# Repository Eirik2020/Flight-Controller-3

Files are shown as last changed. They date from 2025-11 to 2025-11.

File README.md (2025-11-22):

<p align="center" width="100%">
  
</p>

<h1 align="center">Board Name</h1>

<p align="center" width="100%">
  <a href="/actions/workflows/ci.yaml">
    CI Badge
  </a>
</p>

<p align="center" width="100%">
    
</p>

***

<p align="center">
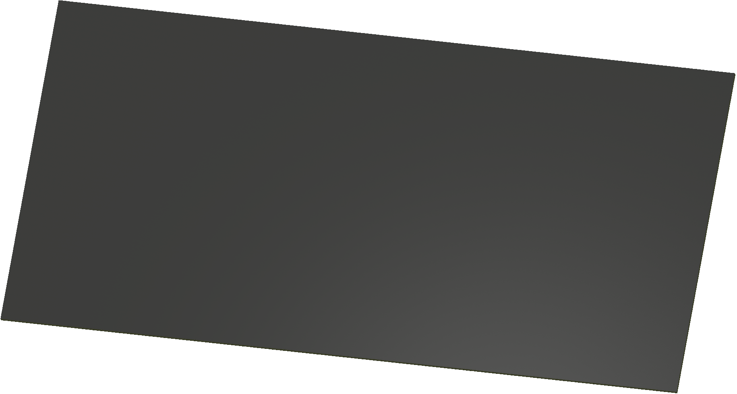
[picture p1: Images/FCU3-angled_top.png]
3D Top Angled
  
&nbsp; &nbsp; &nbsp; &nbsp;
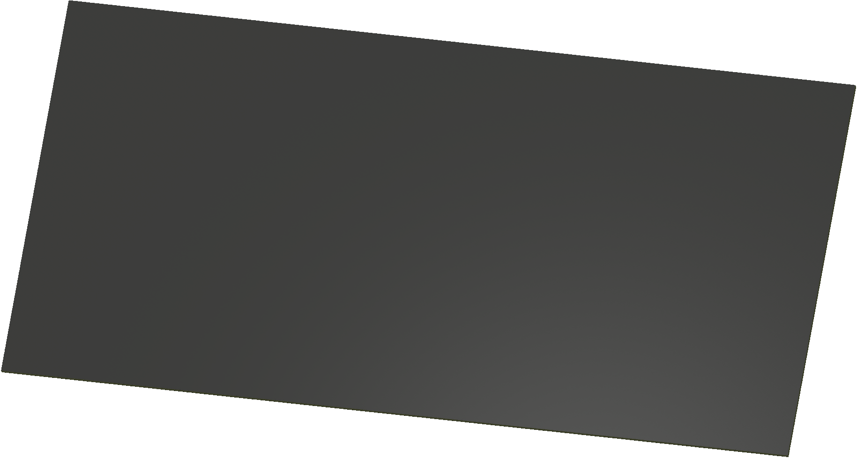
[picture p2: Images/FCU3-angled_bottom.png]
3D Bottom Angled
  
</p>

***

## SPECIFICATIONS

| Parameter | Value | 
| --- | --- |
| Dimensions | N/A × N/A mm |

***

## DIRECTORY STRUCTURE

    .
    ├─ Computations       # Misc calculations
    ├─ HTML               # HTML files for generated webpage
    ├─ Images             # Pictures and renders
    │
    ├─ kibot_resources    # External resources for KiBot
    │  ├─ colors          # Color theme for KiCad
    │  ├─ fonts           # Fonts used in the project
    │  ├─ scripts         # External scripts used with KiBot
    │  └─ templates       # Templates for KiBot generated reports
    │
    ├─ kibot_yaml         # KiBot YAML config files
    ├─ KiRI               # KiRI (PCB diff viewer) files
    │
    ├─ lib                # KiCad footprint and symbol libraries
    │  ├─ 3d_models       # Component 3D models
    │  ├─ lib_fp          # Footprint libraries
    │  └─ lib_sym         # Symbol libraries
    │
    ├─ Logos              # Logos
    │
    ├─ Manufacturing      # Assembly and fabrication documents
    │  ├─ Assembly        # Assembly documents (BoM, pos, notes)
    │  │
    │  └─ Fabrication     # Fabrication documents (ZIP, notes)
    │     ├─ Drill Tables # CSV drill tables
    │     └─ Gerbers      # Gerbers
    │
    ├─ Report             # Reports for ERC/DRC
    ├─ Schematic          # PDF of schematic
    ├─ Templates          # Title block templates
    ├─ Testing
    │  └─ Testpoints      # Testpoints tables      
    │
    └─ Variants           # Outputs for assembly variants

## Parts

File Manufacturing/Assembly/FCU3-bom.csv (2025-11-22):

Row | Quantity Per PCB | References | Value | Datasheet | Footprint | Description | Manufacturer | Manufacturer Part Number | Supplier Part Number
1 | 2 | C15 C16 | 27pF | ~ | C_0603_1608Metric_Pad1.08x0.95mm_HandSolder | Unpolarized capacitor, small symbol
2 | 9 | C3 C4 C5 C6 C12 C13 C14 C17 C18 | 100nF | ~ | C_0603_1608Metric_Pad1.08x0.95mm_HandSolder | Unpolarized capacitor, small symbol
3 | 2 | C1 C2 | 1uF | ~ | C_0603_1608Metric_Pad1.08x0.95mm_HandSolder | Unpolarized capacitor
4 | 3 | C7 C8 C9 | 2.2uF | ~ | C_0603_1608Metric_Pad1.08x0.95mm_HandSolder | Unpolarized capacitor, small symbol
5 | 7 | C10 C11 C19 C20 C21 C22 C23 | 10uF | ~ | C_0603_1608Metric_Pad1.08x0.95mm_HandSolder | Unpolarized capacitor, small symbol
6 | 2 | D1 D2 | SS14 | https://www.vishay.com/docs/88746/ss12.pdf | D_SMA | 40V 1A Schottky Diode, SMA
7 | 5 | J1 J2 J4 J5 J6 | SM06B-SRSS-TB_LF__SN_ |  | JST_SM06B-SRSS-TB_LF__SN_ | Generic connector, double row, 02x03, odd/even pin numbering scheme (row 1 odd numbers, row 2 even numbers), script generated (kicad-library-utils/schlib/autogen/connector/) | JST Same Sky
8 | 1 | PS1 | TPSM84338RCJR |  | TPSM84338RCJR |  | Texas Instruments
9 | 1 | Q2 | SS8050 | http://www.secosgmbh.com/datasheet/products/SSMPTransistor/SOT-23/SS8050.pdf | SOT-23 | General Purpose NPN Transistor, 1.5A Ic, 25V Vce, SOT-23
10 | 1 | R4 | 1k | ~ | R_0603_1608Metric_Pad0.98x0.95mm_HandSolder | Resistor, small symbol
11 | 2 | R7 R10 | 4.7k | ~ | R_0603_1608Metric_Pad0.98x0.95mm_HandSolder | Resistor, small symbol
12 | 2 | R9 R15 | 5.1k | ~ | R_0805_2012Metric_Pad1.20x1.40mm_HandSolder | Resistor
13 | 4 | R2 R3 R8 R11 | 10k | ~ | R_0603_1608Metric_Pad0.98x0.95mm_HandSolder | Resistor, small symbol
14 | 1 | R5 | 18k | ~ | R_0603_1608Metric_Pad0.98x0.95mm_HandSolder | Resistor
15 | 1 | R1 | 75k | ~ | R_0603_1608Metric_Pad0.98x0.95mm_HandSolder | Resistor, small symbol
16 | 1 | R6 | 140k | ~ | R_0603_1608Metric_Pad0.98x0.95mm_HandSolder | Resistor
17 | 1 | S1 | TS32-7-35-BK-B-260-RA-SMT-TR |  | SW_TS32-7-35-BK-B-260-RA-SMT-TR |  | Same Sky
18 | 1 | U3 | MCP1700x-330xxTT | http://ww1.microchip.com/downloads/en/DeviceDoc/20001826D.pdf | SOT-23 | 250mA Low Quiscent Current LDO, 3.3V output, SOT-23
19 | 1 | U1 | MPU-6500 |  | QFN40P300X300X95-25N |  | TDK InvenSense
20 | 1 | U5 | STM32F405RGTx | https://www.st.com/resource/en/datasheet/stm32f405rg.pdf | LQFP-64_10x10mm_P0.5mm | STMicroelectronics Arm Cortex-M4 MCU, 1024KB flash, 192KB RAM, 168 MHz, 1.8-3.6V, 51 GPIO, LQFP64
21 | 1 | Y1 | LFXTAL055207Bulk | ~ | Crystal_HC49-4H_Vertical | Two pin crystal

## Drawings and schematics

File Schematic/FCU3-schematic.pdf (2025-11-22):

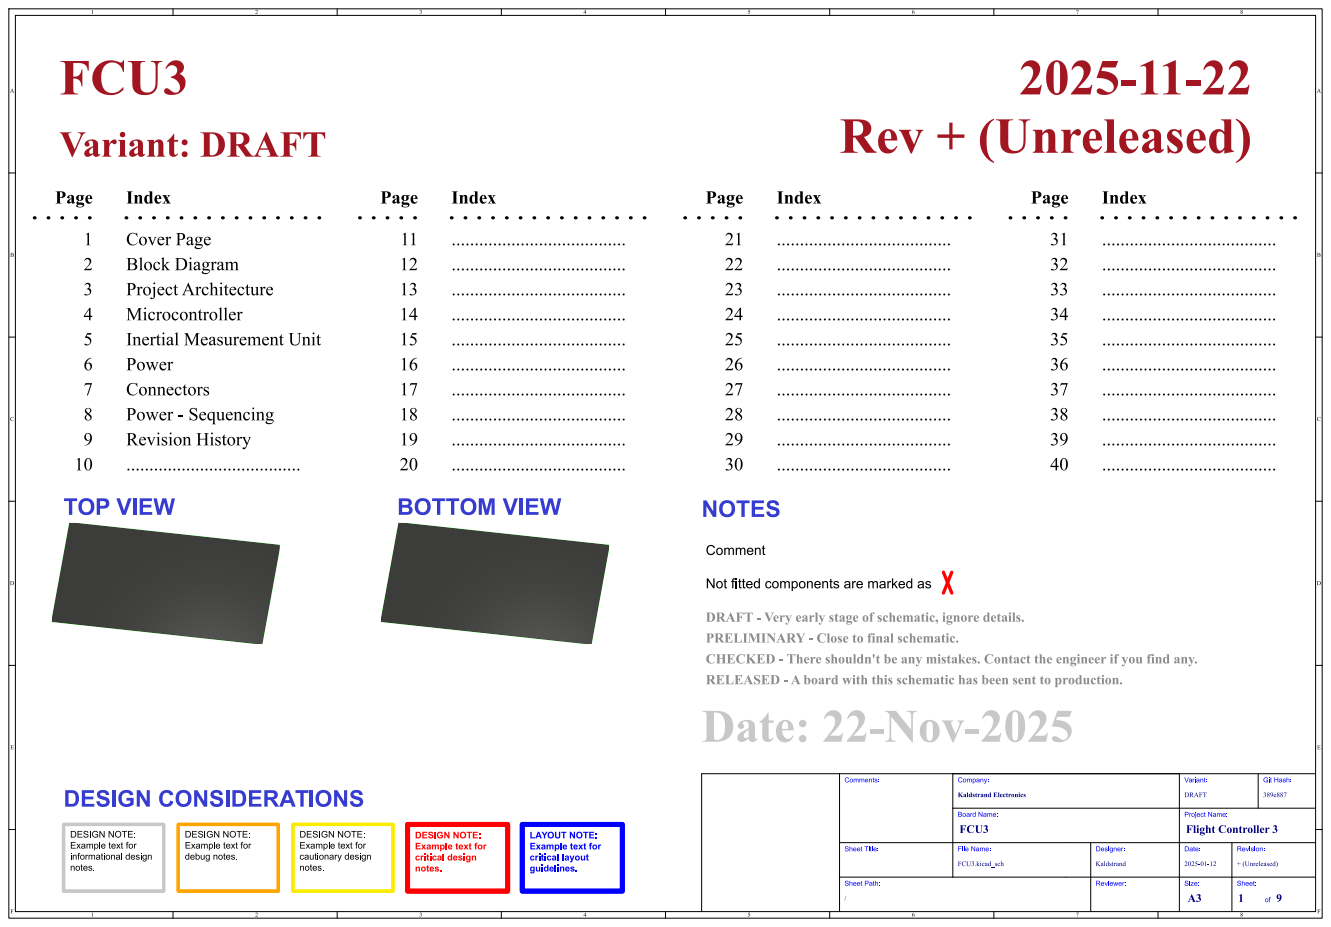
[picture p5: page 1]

...................................... Date:22-Nov-2025
CHECKED - Thereshouldn'tbeanymistakes.Contacttheengineerif youfindany. ......................................

Not fitted components are marked as

DRAFT - Veryearlystageof schematic,ignoredetails.

Revision: + (Unreleased) Date: Project Name: 2025-01-12 Reviewer: Designer:

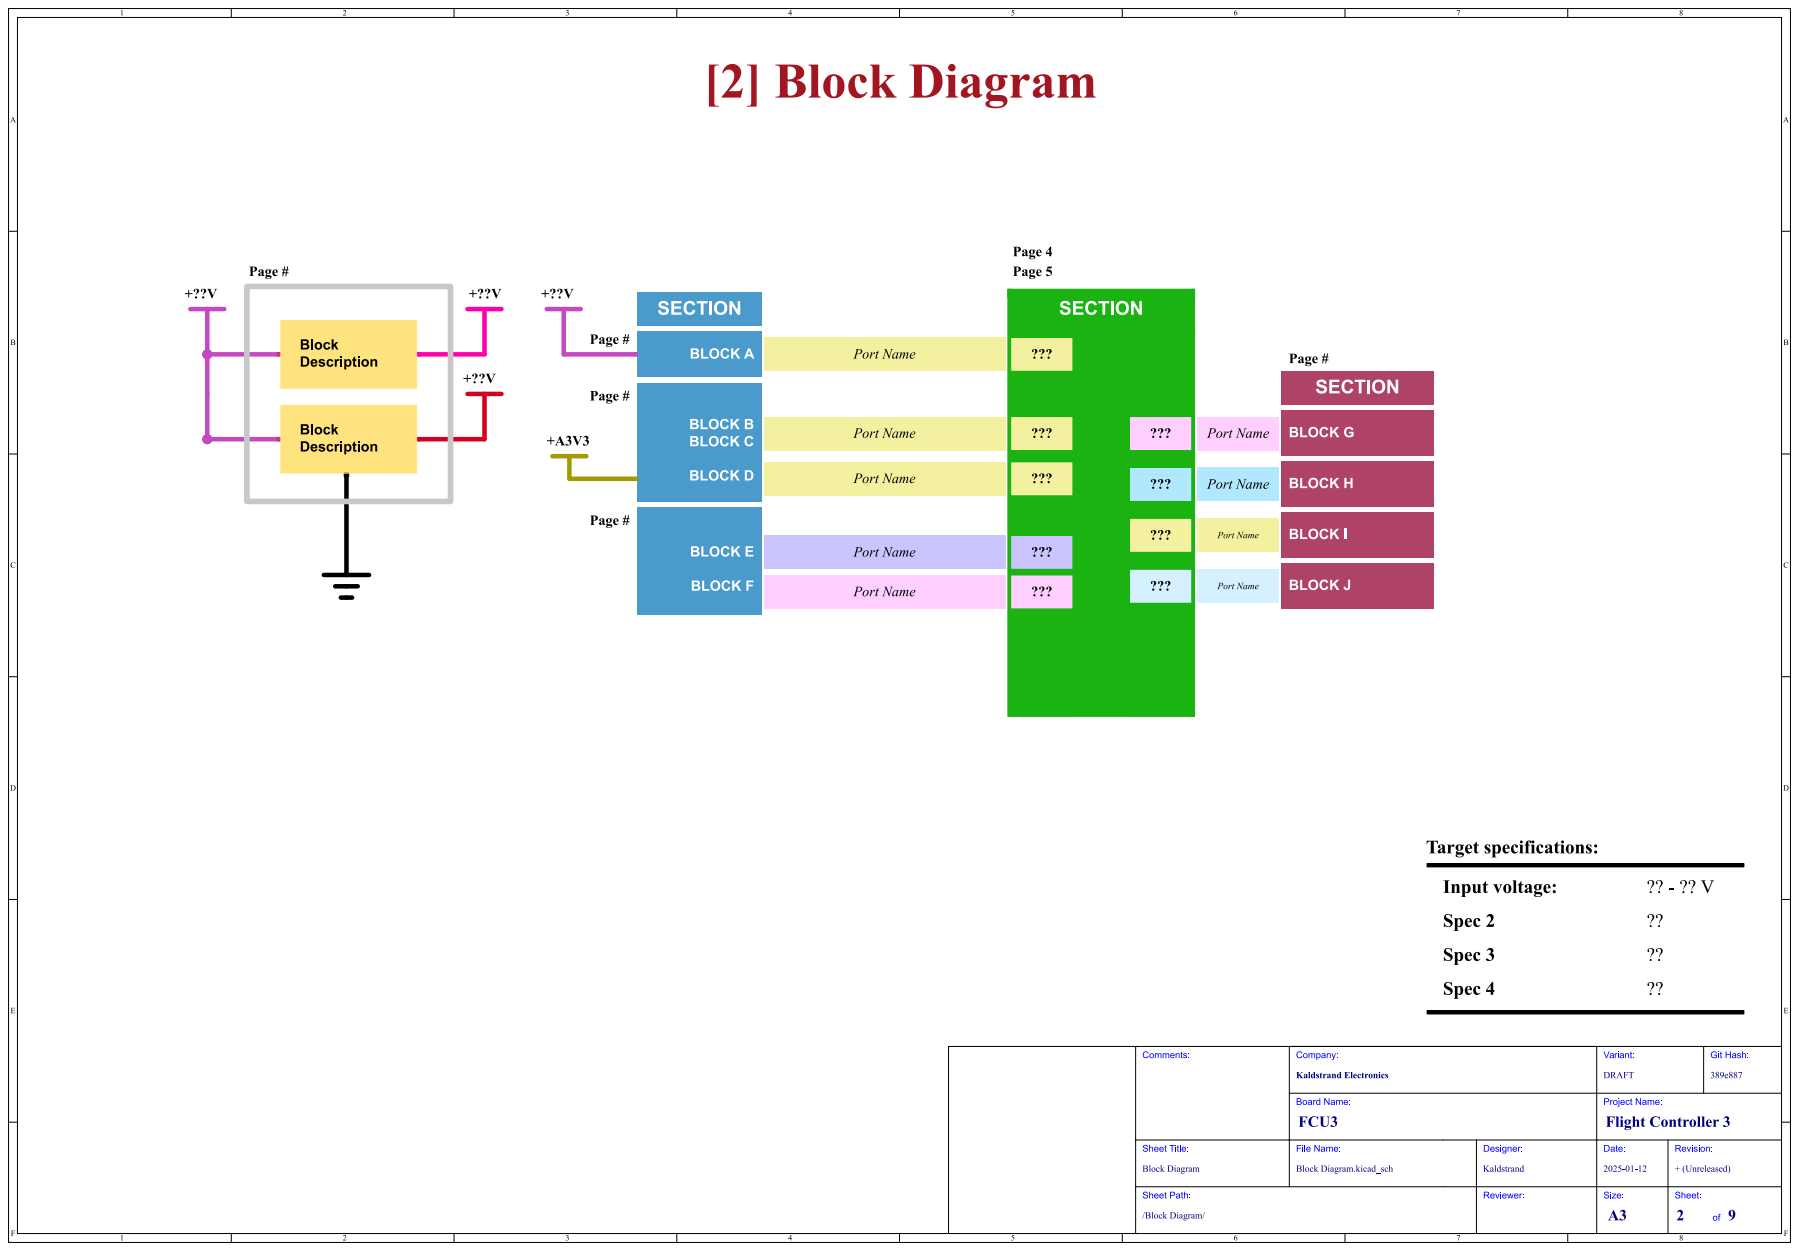
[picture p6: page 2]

Port Name | ??? | Port Name

BLOCK G

Port Name

/Block Diagram/ Sheet Path: Block Diagram

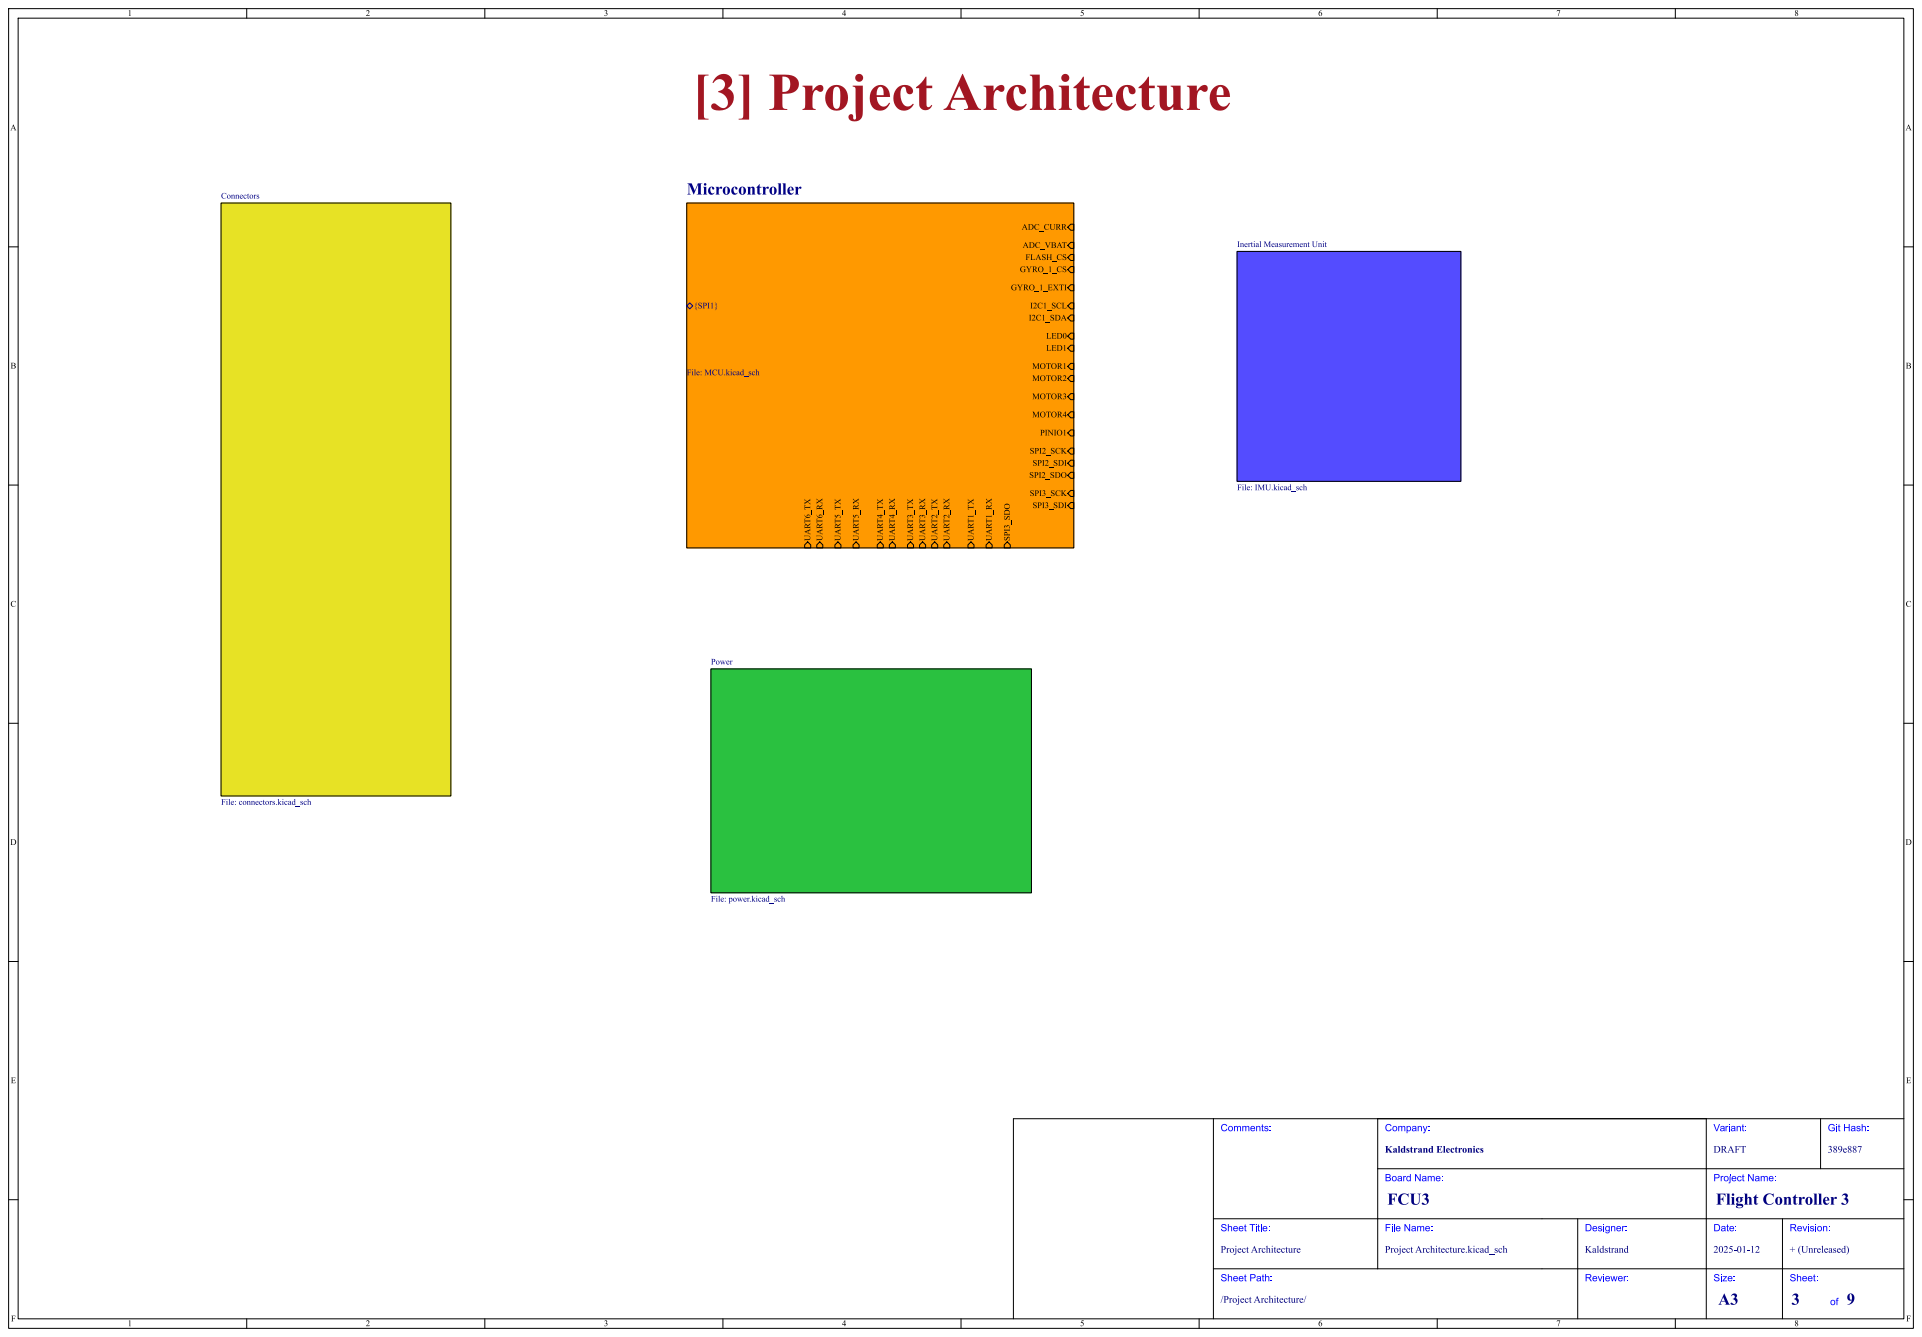
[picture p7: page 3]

Inertial MeasurementUnit File: IMU.kicad_sch Power File: power.kicad_sch

Revision: + (Unreleased) Date: Project Name: 2025-01-12 Reviewer: Designer:

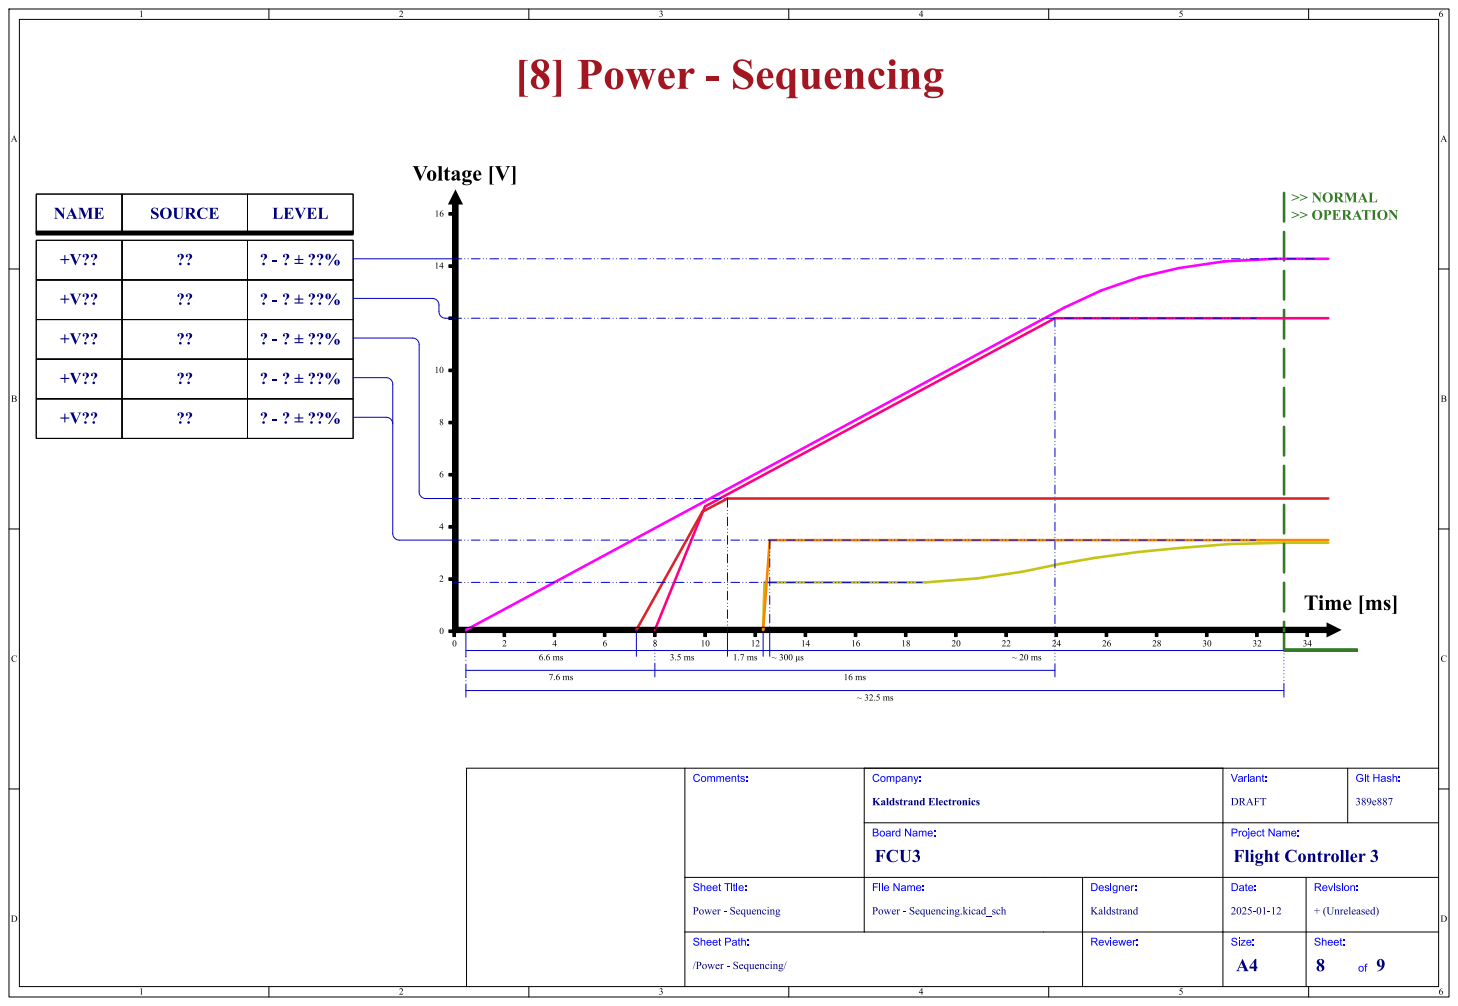
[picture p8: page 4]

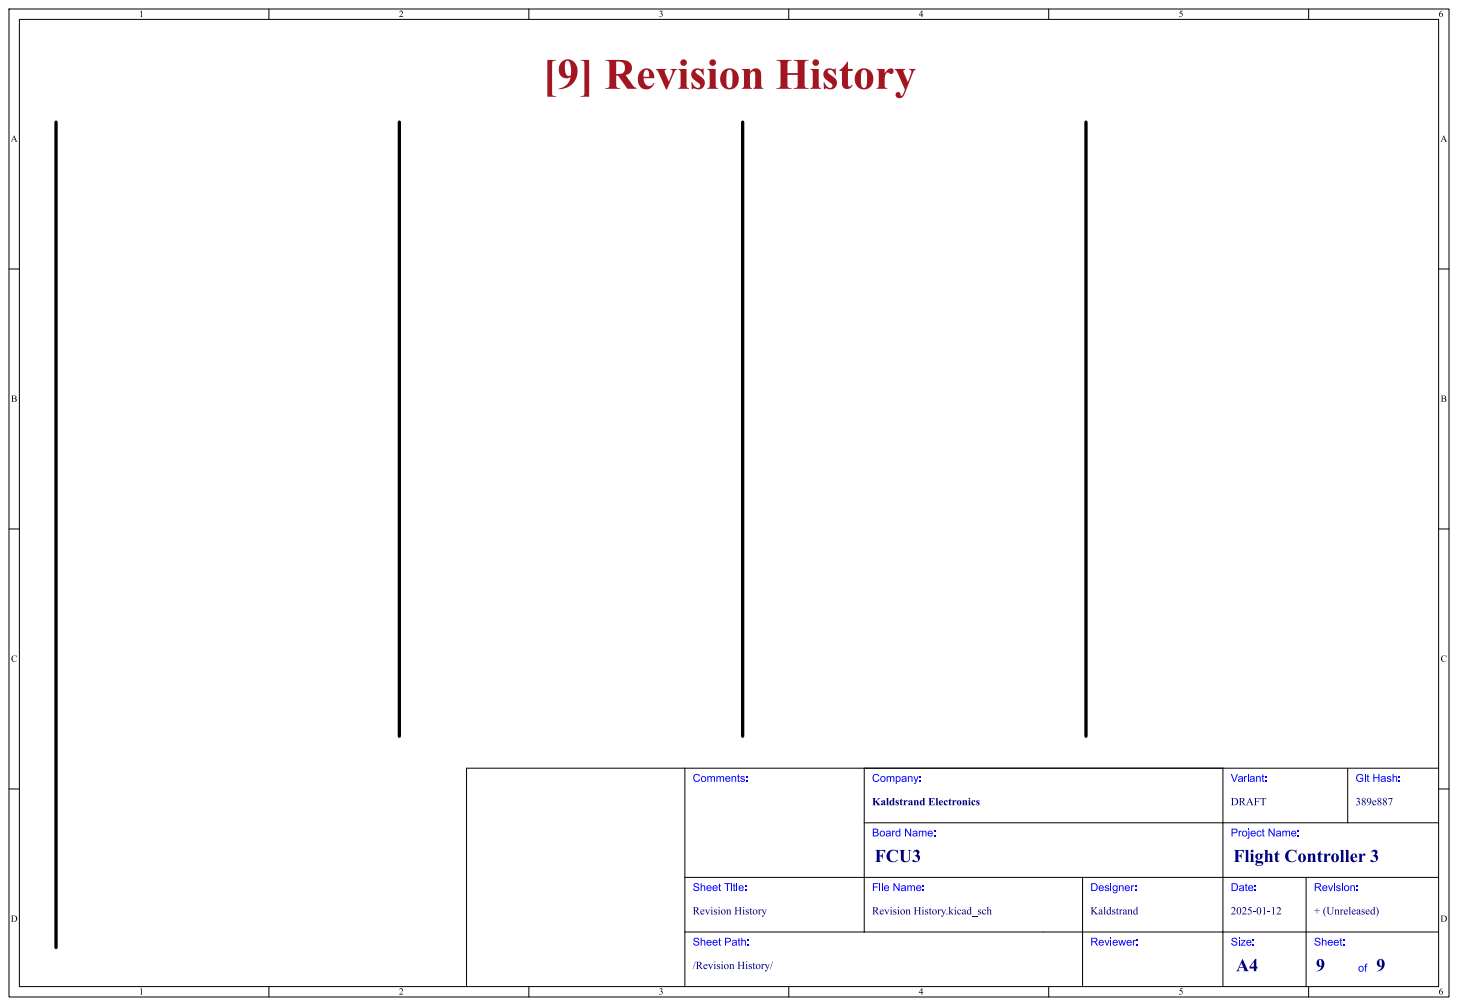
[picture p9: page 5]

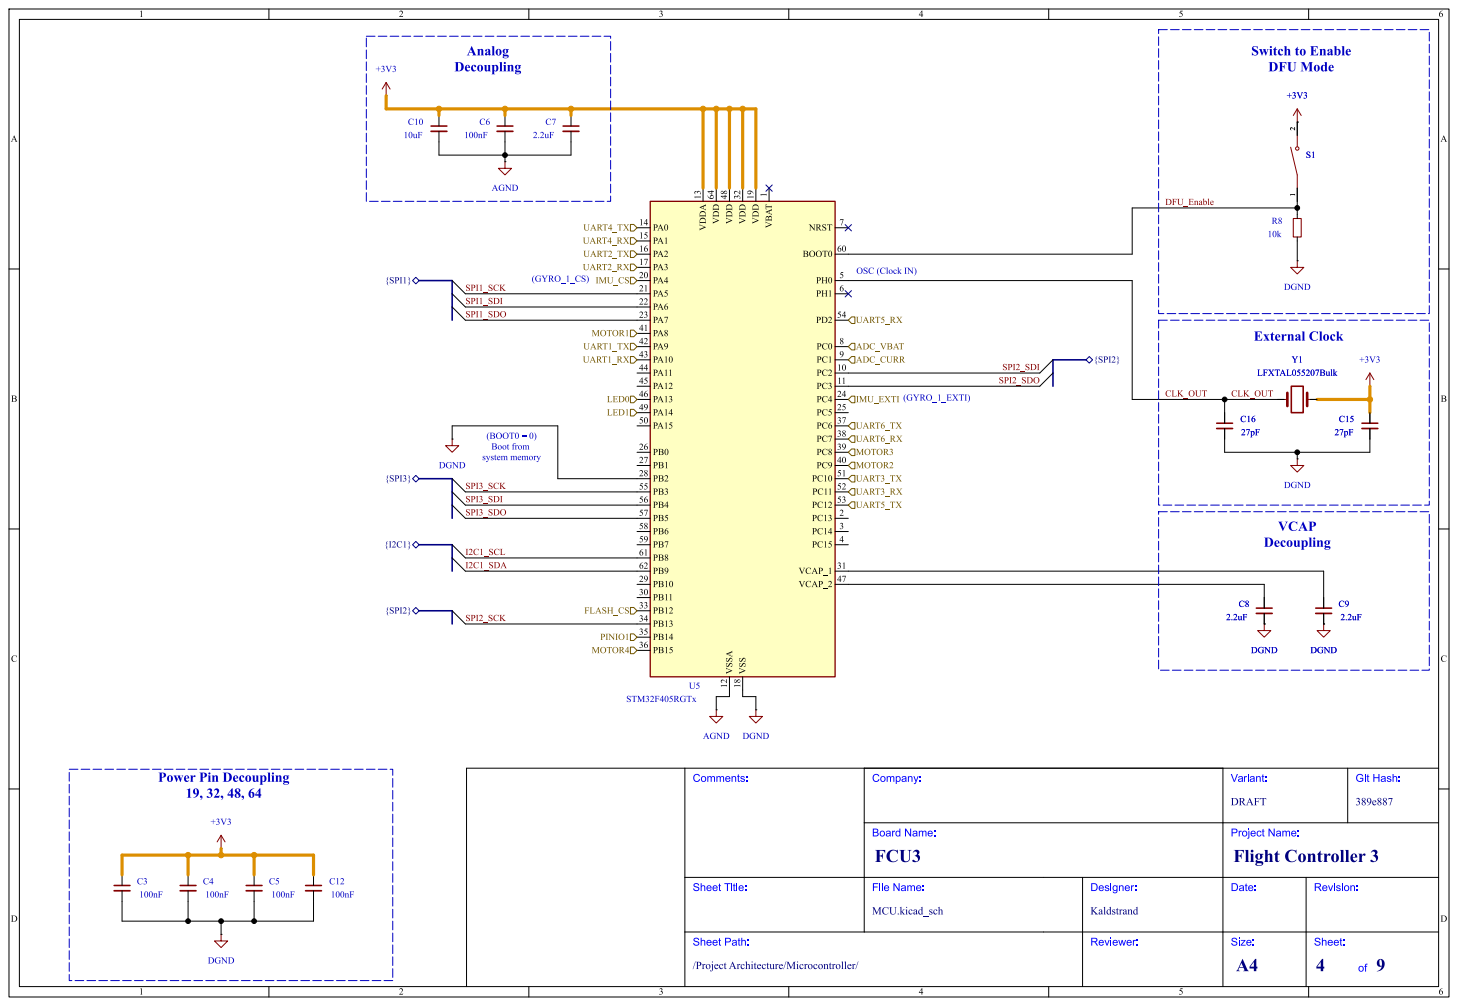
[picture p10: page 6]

1 VDD 19 VDD 32 VSS 18 VDD 48 VSSA 12 VDD 64 VDDA 13 PA0 14 PA1 15 PA2 16 PA3 17 PA4 20 PA5 21 PA6 22 PA7 23 PA8 41 PA9 42 PA10 43 PA11 44 PA12 45 PA13 46 PA14 49 PA15 50 PB0 26 PB1 27 PB2 28 PB3 55 PB4 56 PB5 57 PB6 58 PB7 59 PB8 61 PB9 62 PB10 29 PB11 30 PB12 33 PB13 34 PB14 35 PB15 36 U5 STM32F405RGTx

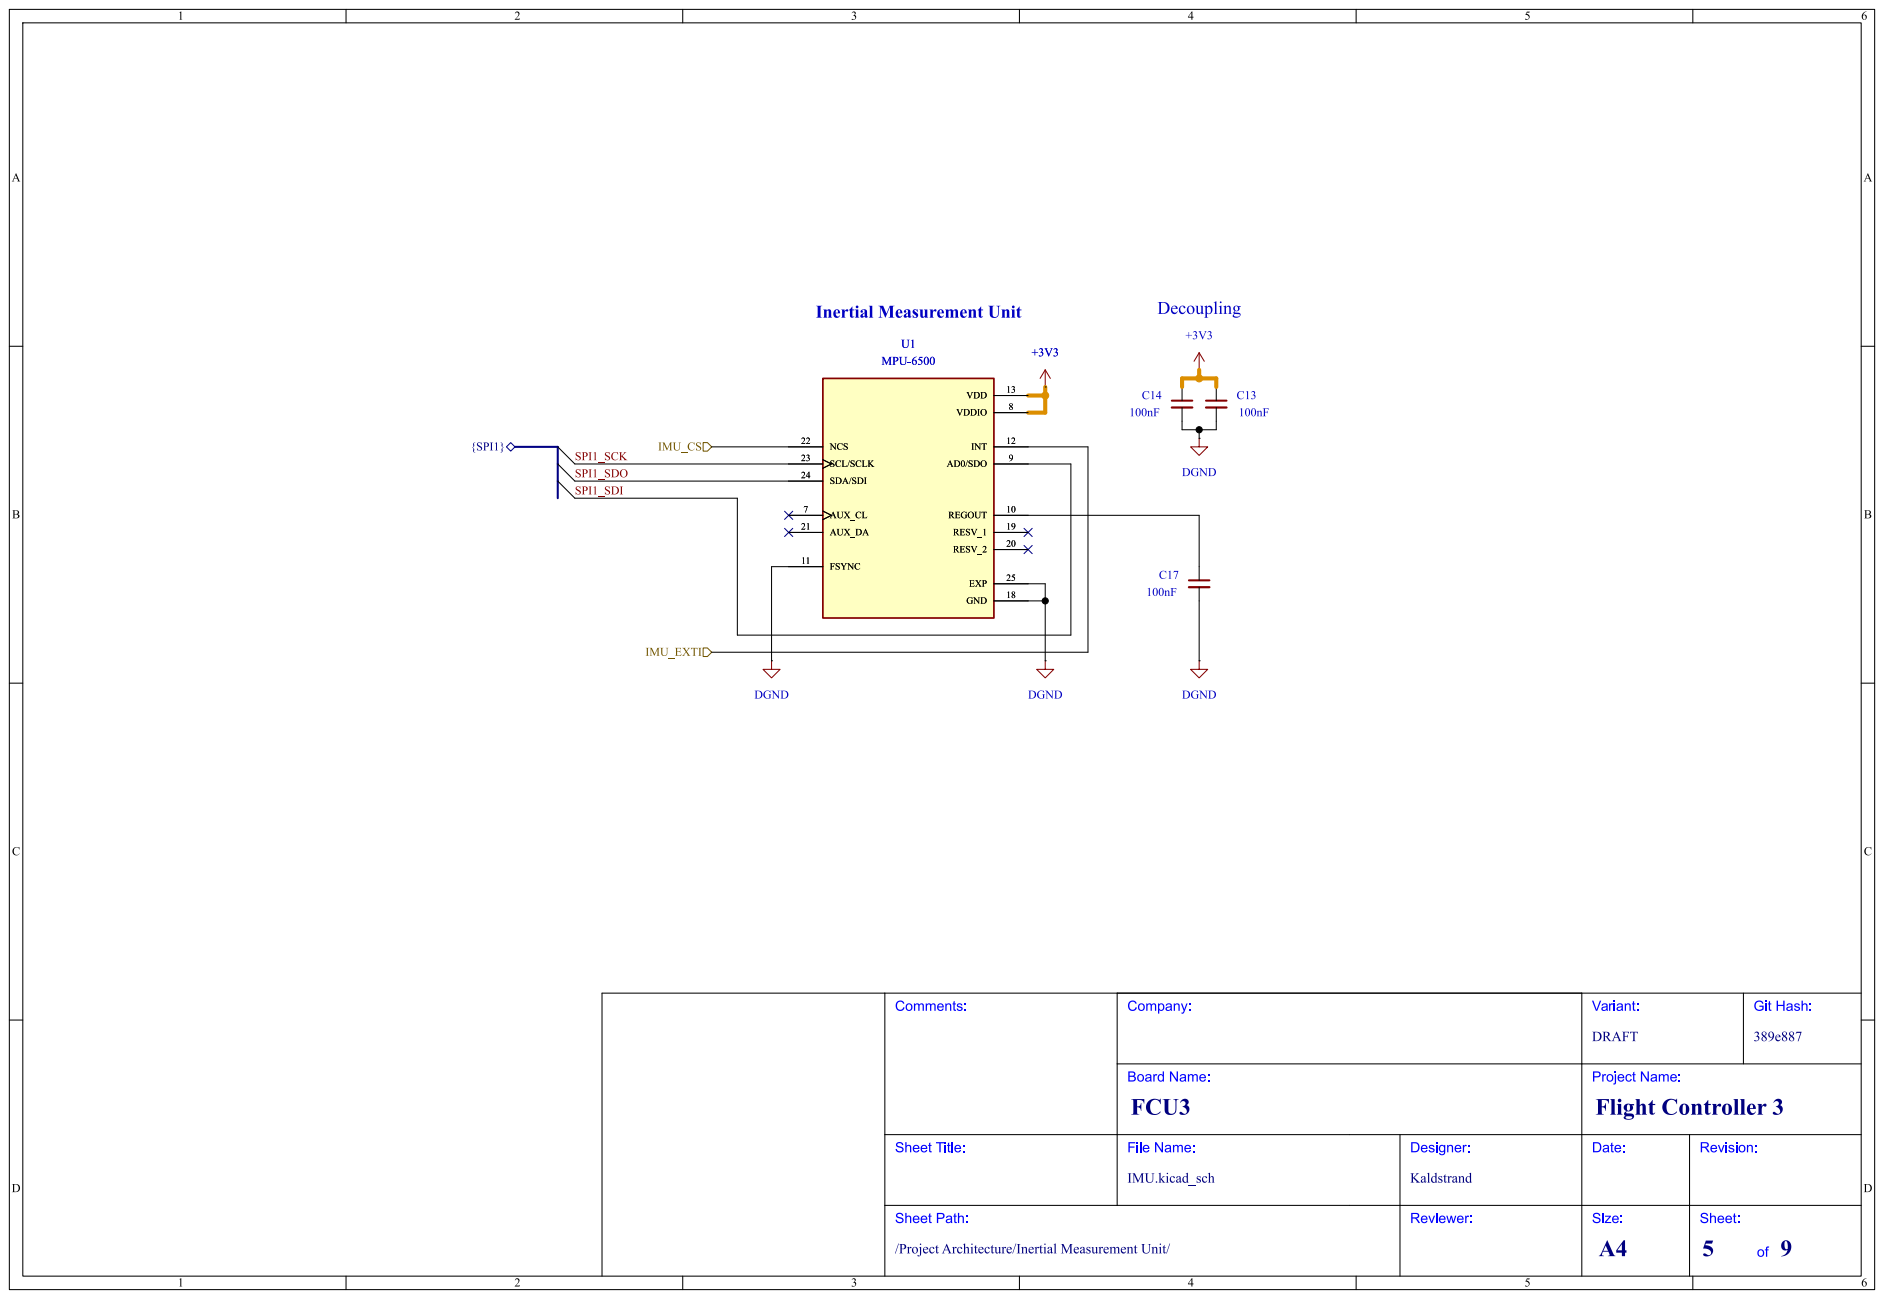
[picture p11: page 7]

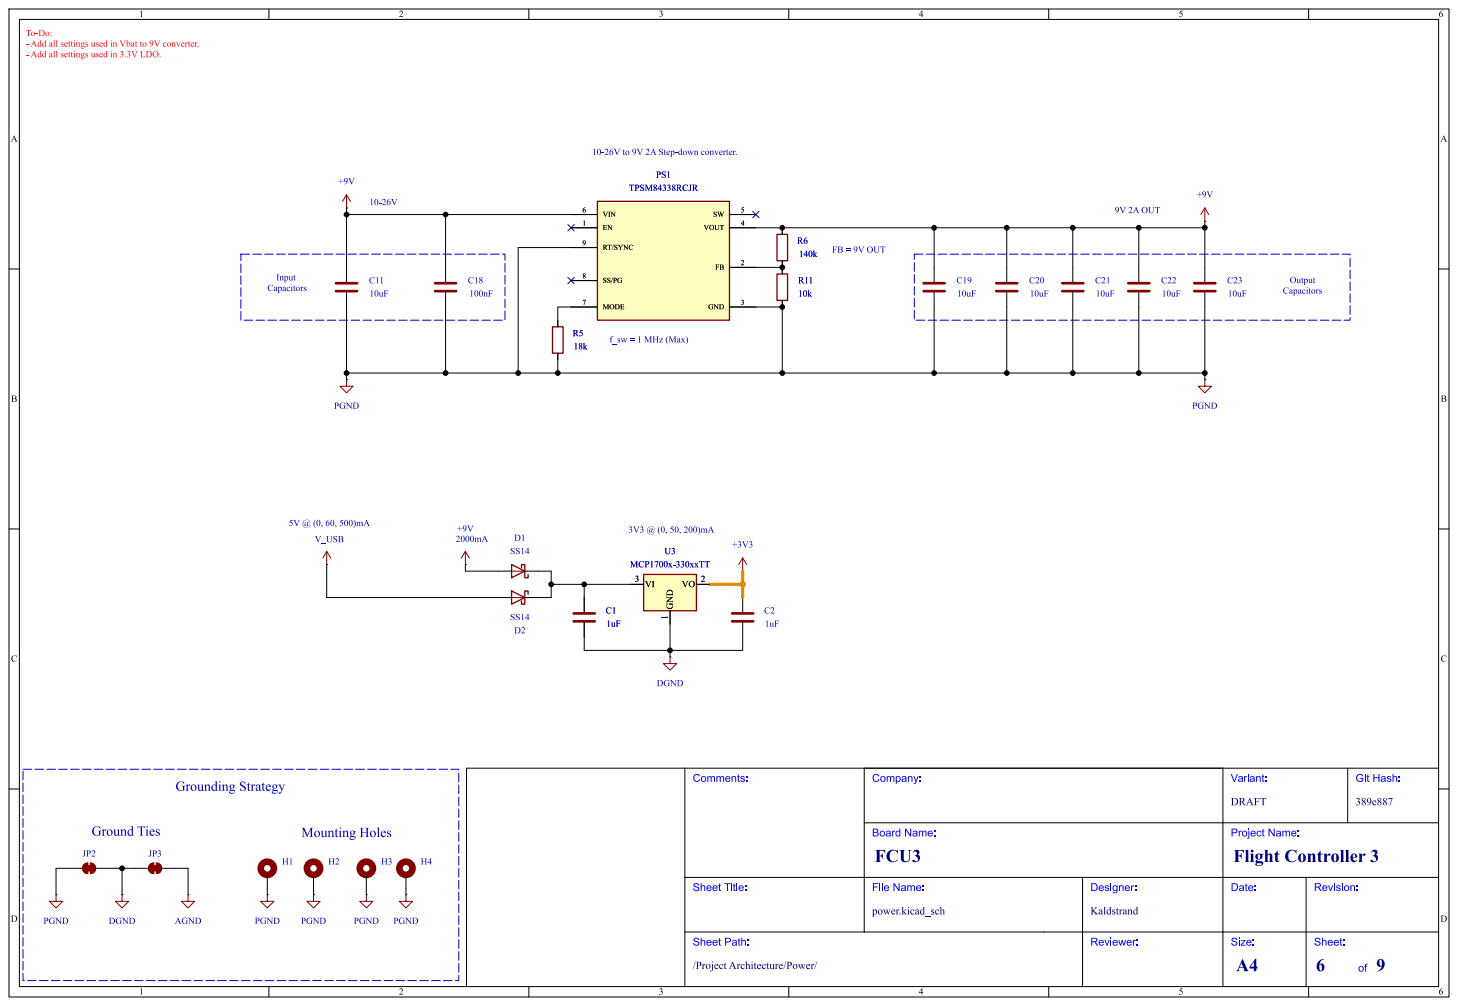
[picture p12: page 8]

f_sw = 1 MHz (Max) 10-26Vto 9V 2A Step-downconverter. 3V3 @(0, 50,200)mA

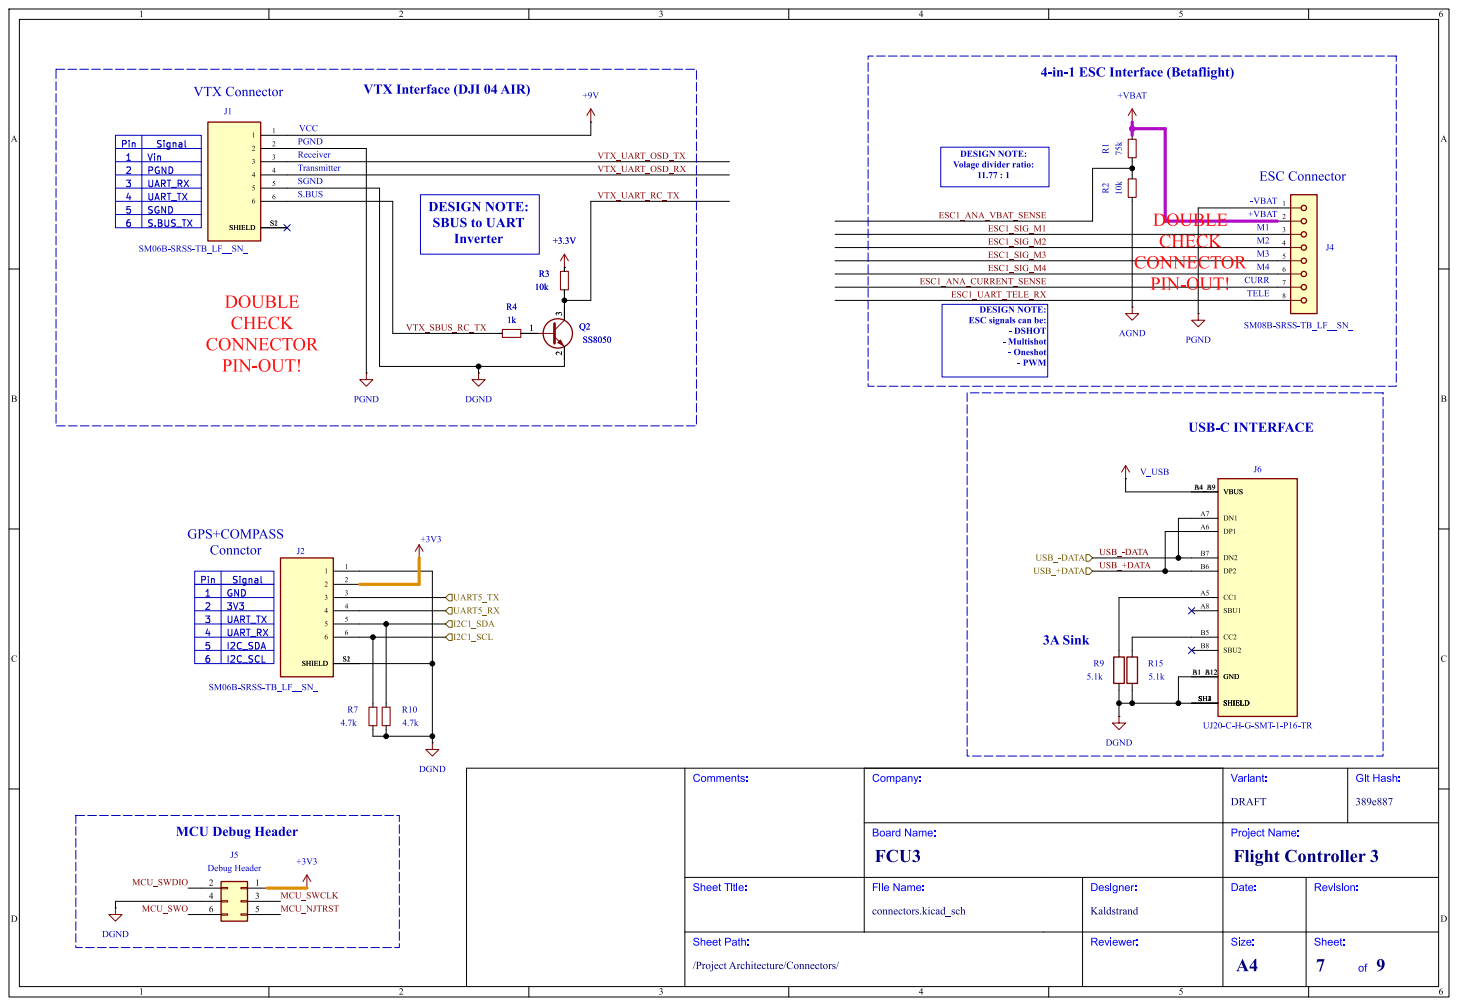
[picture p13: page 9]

2 | PGND
3 | UART_RX
4 | UART_TX
5 | SGND

2 | 3V3
3 | UART_TX
4 | UART_RX
5 | I2C_SDA
6 | I2C_SCL

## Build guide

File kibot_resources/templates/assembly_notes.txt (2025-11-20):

ASSEMBLY NOTES (UNLESS OTHERWISE SPECIFIED)

1)	DO NOT POPULATE PARTS ARE MARKED WITH A RED CROSS.

2)	DO NOT POPULATE PARTS ARE NOT PRESENT IN THE BOM.

3)	IF CONFLICTING INFORMATION IS FOUND BETWEEN THE ASSEMBLY
	FILE AND BOM, BOM SHOULD BE USED AS THE MAIN SOURCE.

4)	CONFORMAL COATING IS NOT REQUIRED.

5)	DOT IDENTIFIES PIN #1 LOCATION AND DEVICE ORIENTATION
	WHEN VIEWED FROM THE TOP.

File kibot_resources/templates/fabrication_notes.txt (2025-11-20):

FABRICATION NOTES (UNLESS OTHERWISE SPECIFIED)

1)	FABRICATE PER IPC-6012A CLASS 2.

2)	OUTLINE DEFINED IN SEPARATE GERBER FILE WITH
	"Edge_Cuts.GBR" SUFFIX.

	DIMENSIONS OF CIRCUMSIZED RECTANGLE SHOWN ON THIS
	DRAWING FOR REFERENCE ONLY.

3)	SEE SEPARATE DRILL FILES WITH ".DRL" SUFFIX 
	FOR HOLE LOCATIONS.

	SELECTED HOLE LOCATIONS SHOWN ON THIS DRAWING 
	FOR REFERENCE ONLY.

4)	SURFACE FINISH: ${pcb_finish_cap}

5)	SOLDERMASK ON BOTH SIDES OF THE BOARD SHALL 
	BE LPI, COLOR ${solder_mask_color_text_cap}.

6)	SILK SCREEN LEGEND TO BE APPLIED PER LAYER 
	STACKUP USING ${silk_screen_color_text_cap} NON-CONDUCTIVE EPOXY INK.

7)	ALL VIAS ARE TENTED ON BOTH SIDES UNLESS 
	SOLDERMASK OPENED IN GERBER.

8)	VENDOR SHOULD FOLLOW ROHS COMPLIANT PROCESS 
	AND Pb FREE FOR MANUFACTURING

9)	PCB MATERIAL REQUIREMENTS:

	A.	FLAMMABILITY RATING MUST MEET OR EXCEED 
		UL94V-0 REQUIREMENTS.
	B.	Tg 170 C OR EQUIVALENT.
	C.	EQUIVALENT MATERIAL SHALL BE RoHS COMPLIANT, 
		HALOGEN FREE AND APPROVED BY ${COMPANY_cap}.

10)	DESIGN GEOMETRY MINIMUM FEATURE SIZES:

	BOARD SIZE				${bb_w_mm} × ${bb_h_mm} mm
	BOARD THICKNESS		${thickness_mm} mm
	TRACE WIDTH			${track_mm} mm
	TRACE TO TRACE		${clearance_mm} mm
	MIN. HOLE (PTH)			${drill_pth_real_mm} mm
	MIN. HOLE (NPTH)		${drill_npth_real_mm} mm
	ANNULAR RING			${oar_mm} mm
	COPPER TO HOLE		${c2h_mm} mm
	COPPER TO EDGE		${c2e_mm} mm
	HOLE TO HOLE			${h2h_mm} mm
#?stackup and impedance_controlled

#?stackup and impedance_controlled
11)	REFER TO IMPEDANCE TABLE FOR IMPEDANCE CONTROL REQUIREMENTS.
#?stackup and impedance_controlled

#?stackup and impedance_controlled
12)	CONFIRM SPACE WIDTHS AND SPACINGS.

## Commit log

2025-11-22 First Draft
    [FCU3.kicad_sch, IMU.kicad_sch, MCU.kicad_sch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]
2025-11-22 Update Outputs
    [FCU3-bom.csv]
